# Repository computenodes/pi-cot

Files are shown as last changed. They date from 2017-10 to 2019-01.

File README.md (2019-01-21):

# Pi-iC880a



Adapter board to interface between the Raspberry Pi and the [iC880a LoRaWAN](https://wireless-solutions.de/products/radiomodules/ic880a.html) concentrator.  It also supports an EEPROM for HAT identification, DS3231 RTC chip for maintaining time between powercycles, and a [DHT-22](http://www.hobbytronics.co.uk/rht03-humidity-temp-sensor?keyword=dht22) for temperature/humidity sensing.

This board supports using 3 different GPS modules for the timing/positioning
 1. [Adafruit Ultimate GPS module](https://www.adafruit.com/product/746) soldered onto the board.  
 1. The MT3339 GPS modules (as used on the adafruit break out board) soldered directly to the PCB.  
 1. Ublox LEA-6T soldered onto the iC880a Concentrator.
 
 ## GPS Options
 In order to support the different GPS options there are solder jumpers on the PCB to link the required lines.  There are 3 jumpers: TX, RX, PPS.  The jumpers for TX & RX need to be used whichever GPS module is in use.  The PPS link is needed if using either the Ultimate GPS, or the MT3339.
 
 ## Backup battery options
 There are also pads for 0 ohm resistors to enable a choice of which peripherals have the backup battery connected.  These can either be popuplated with 0ohm resistors, or just bridged using solder.
 
 ## Enabling the UBlox module
 All GPIOs from the iC880a board are connected to the Pi.  In order to enable the UBlox module on the iC880a a couple of these need to be configured as shown below.
 
 | Pi I/O | Function | Pin State |
 | ------ | -------- | --------- |
 |  23    |  GPS  EN | HIGH      |
 |  27    | !GPS RST | HIGH      |

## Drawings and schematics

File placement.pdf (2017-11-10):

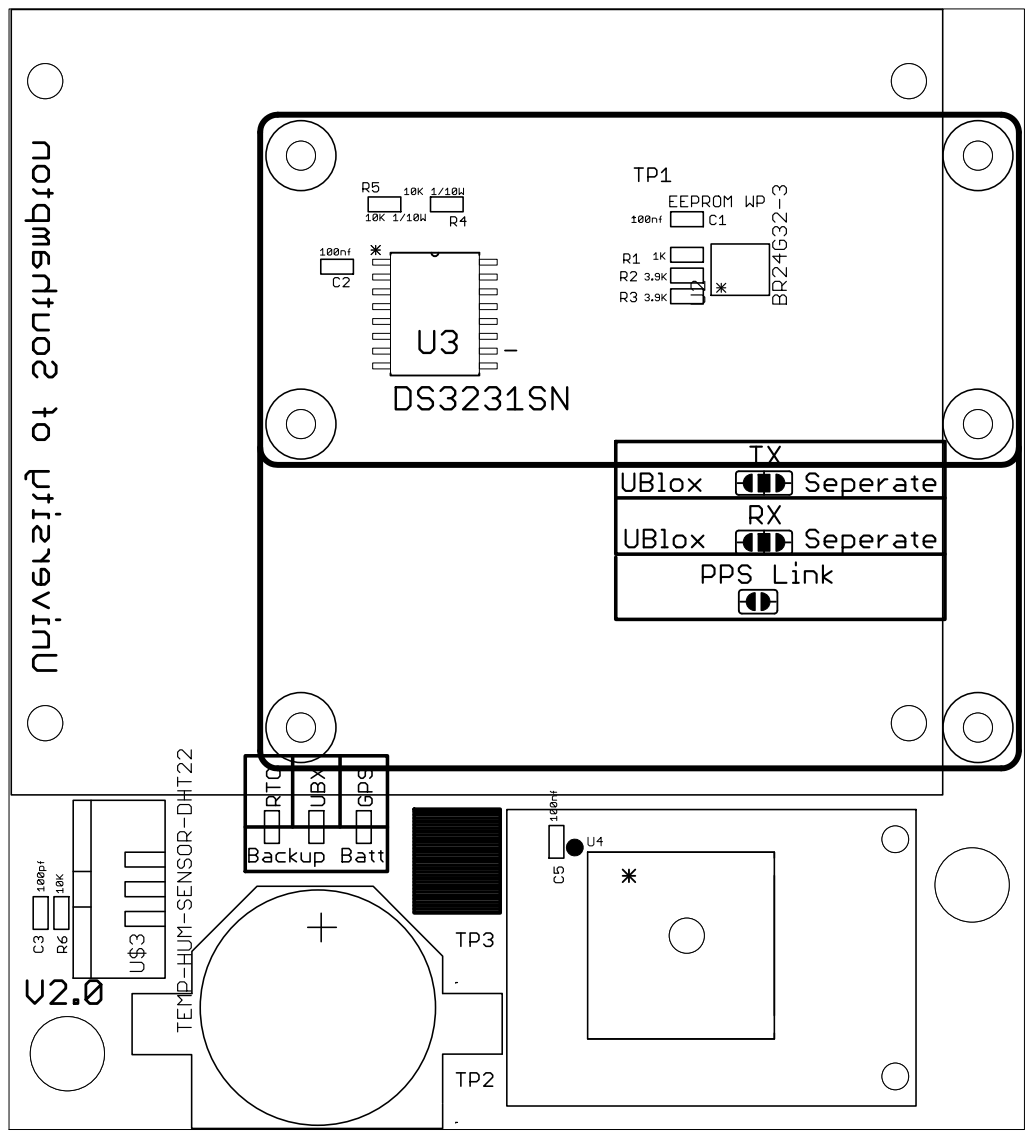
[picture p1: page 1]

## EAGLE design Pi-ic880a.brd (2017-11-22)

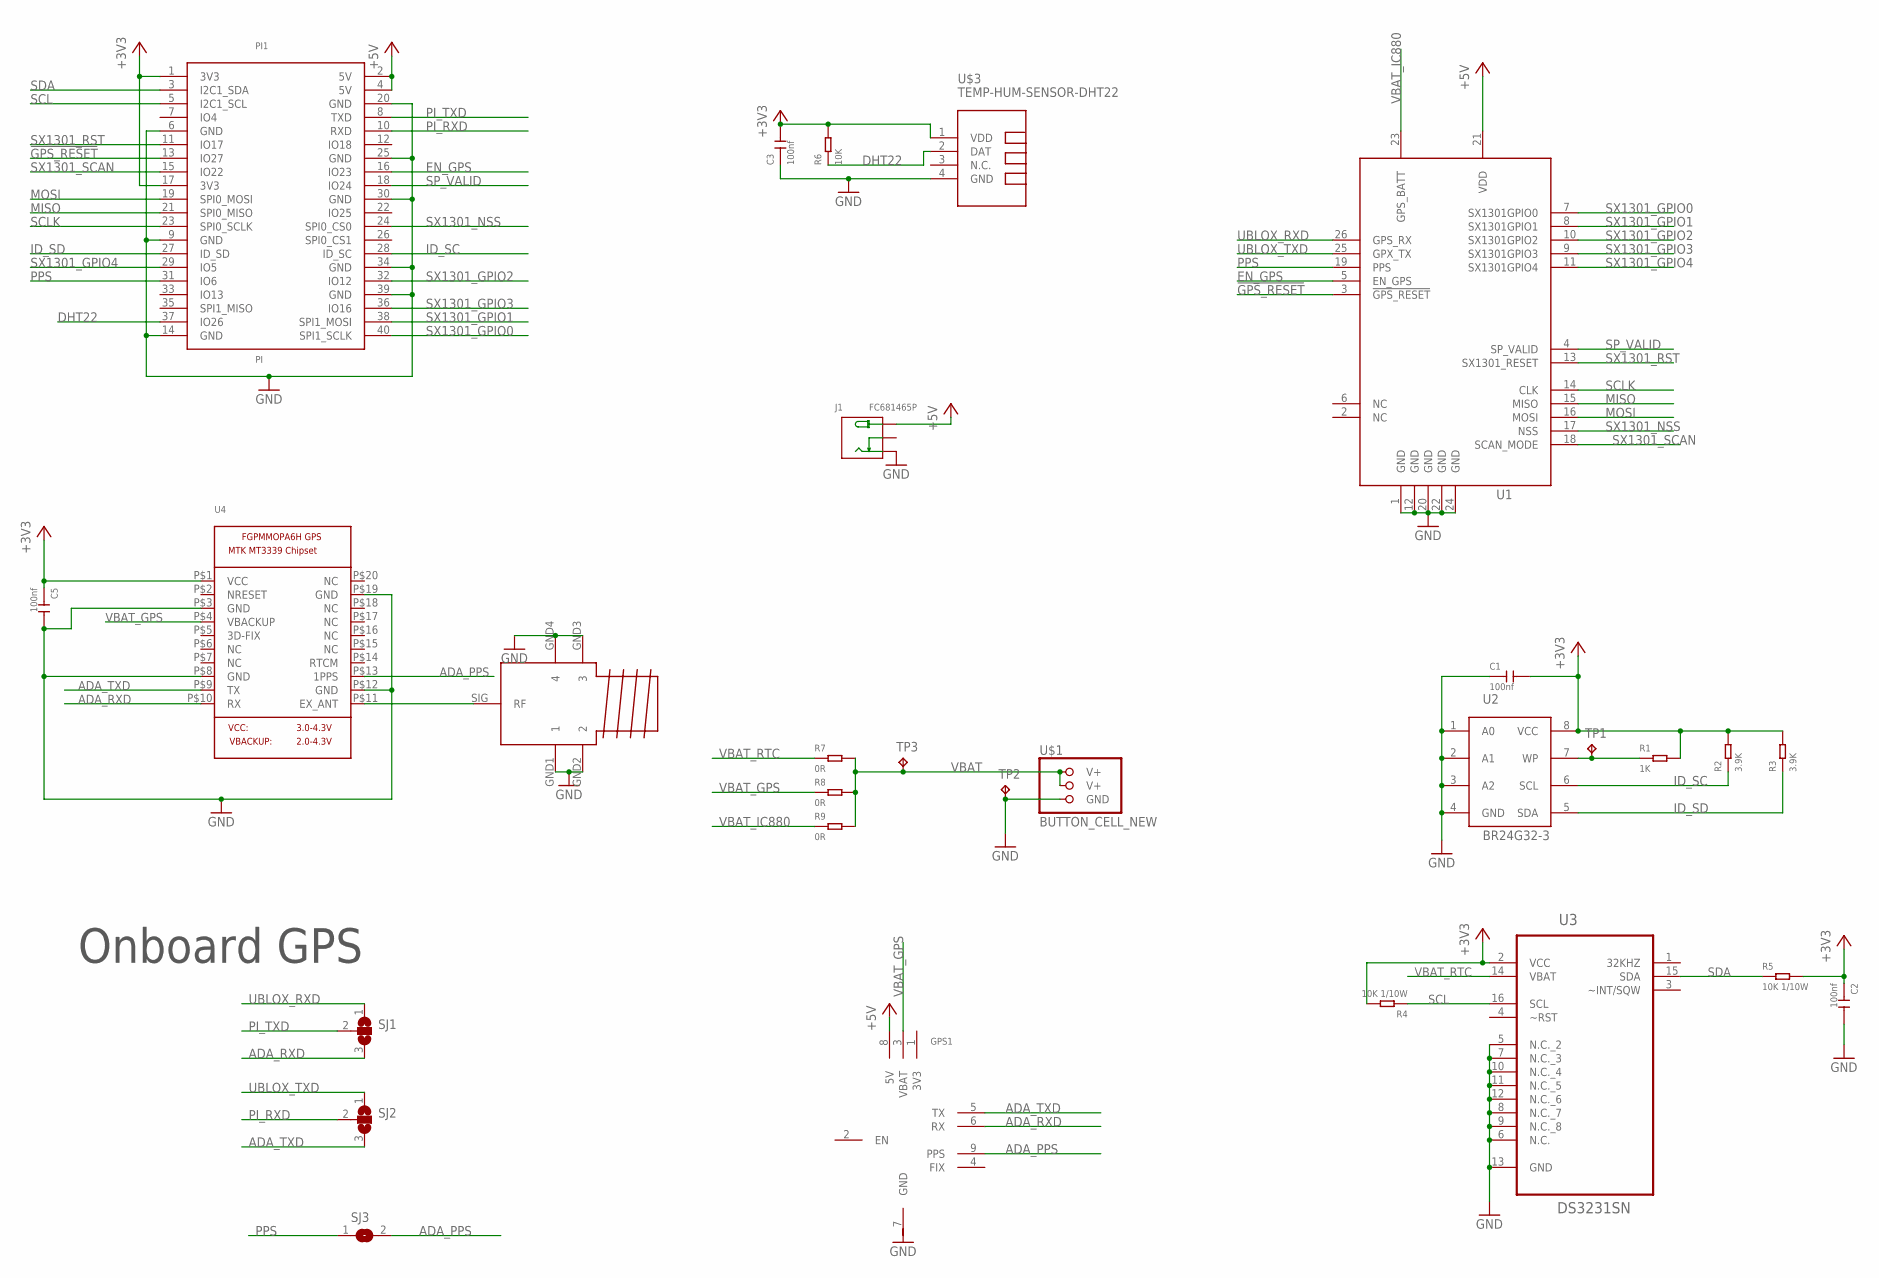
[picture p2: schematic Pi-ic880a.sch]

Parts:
C1, C2, C3, C5: 100nf; C0603
GPS1: ULTIMATE-GPS
J1: FC681465P
PI1: PI
R1: 1K; R0603
R2, R3: 3.9K; R0603
R4, R5: 10K 1/10W; R0603
R6: 10K; R0603
R7, R8, R9: 0R; R0603
SJ1, SJ2: SJ2W; SJ_2
SJ3: SJ
TP1, TP2, TP3: TPB2,54; B2,54
U1: IC880A
U2: BR24G32-3; SOP8
U3: DS3231SN; SOIC127P1032X265-16N
U4: GPS_FGPMMOPA6H; FGPMMOPA6H
U$1: BUTTON_CELL_NEW; CR2016
U$2: SMATH; SMA
U$3: TEMP-HUM-SENSOR-DHT22

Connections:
3V3: GPS1.1 (3V3)
!GPS_RESET: PI1.13 (IO27), U1.3 (!GPS_RESET)
+3V3: C1.2, C2.1, C3.2, C5.1, PI1.1 (3V3), PI1.17 (3V3), R1.2, R2.2, R3.2, R4.2, R5.2, R6.2, U2.8 (VCC), U3.2 (VCC), U4.P$1 (VCC), U$3.1 (VDD)
+5V: GPS1.8 (5V), J1.1 (+), PI1.2 (5V), PI1.4 (5V), U1.21 (VDD)
ADA_PPS: GPS1.9 (PPS), SJ3.2, U4.P$13 (1PPS)
ADA_RXD: GPS1.6 (RX), SJ1.3, U4.P$10 (RX)
ADA_TXD: GPS1.5 (TX), SJ2.3, U4.P$9 (TX)
DHT22: PI1.37 (IO26), R6.1, U$3.2 (DAT)
EN_GPS: PI1.16 (IO23), U1.5 (EN_GPS)
GND: C1.1, C2.2, C3.1, C5.2, GPS1.7 (GND), J1.3 (-), PI1.6 (GND), PI1.9 (GND), PI1.14 (GND), PI1.20 (GND), PI1.25 (GND), PI1.30 (GND), PI1.34 (GND), PI1.39 (GND), TP2.TP, U1.1 (GND), U1.12 (GND), U1.20 (GND), U1.22 (GND), U1.24 (GND), U2.1 (A0), U2.2 (A1), U2.3 (A2), U2.4 (GND), U3.5 (N.C._2), U3.6 (N.C.), U3.7 (N.C._3), U3.8 (N.C._7), U3.9 (N.C._8), U3.10 (N.C._4), U3.11 (N.C._5), U3.12 (N.C._6), U3.13 (GND), U4.P$3 (GND), U4.P$8 (GND), U4.P$12 (GND), U4.P$19 (GND), U$1.GND, U$2.GND1 (1), U$2.GND2 (2), U$2.GND3 (3), U$2.GND4 (4), U$3.4 (GND)
GPS_ANT: U4.P$11 (EX_ANT), U$2.SIG (RF)
ID_SC: PI1.28 (ID_SC), R2.1, U2.6 (SCL)
ID_SD: PI1.27 (ID_SD), R3.1, U2.5 (SDA)
MISO: PI1.21 (SPI0_MISO), U1.15 (MISO)
MOSI: PI1.19 (SPI0_MOSI), U1.16 (MOSI)
PI_RXD: PI1.10 (RXD), SJ2.2
PI_TXD: PI1.8 (TXD), SJ1.2
PPS: PI1.31 (IO6), SJ3.1, U1.19 (PPS)
SCL: PI1.5 (I2C1_SCL), R4.1, U3.16 (SCL)
SCLK: PI1.23 (SPI0_SCLK), U1.14 (CLK)
SDA: PI1.3 (I2C1_SDA), R5.1, U3.15 (SDA)
SP_VALID: PI1.18 (IO24), U1.4 (SP_VALID)
SX1301_GPIO0: PI1.40 (SPI1_SCLK), U1.7 (SX1301GPIO0)
SX1301_GPIO1: PI1.38 (SPI1_MOSI), U1.8 (SX1301GPIO1)
SX1301_GPIO2: PI1.32 (IO12), U1.10 (SX1301GPIO2)
SX1301_GPIO3: PI1.36 (IO16), U1.9 (SX1301GPIO3)
SX1301_GPIO4: PI1.29 (IO5), U1.11 (SX1301GPIO4)
SX1301_NSS: PI1.24 (SPI0_CS0), U1.17 (NSS)
SX1301_RST: PI1.11 (IO17), U1.13 (SX1301_RESET)
SX1301_SCAN: PI1.15 (IO22), U1.18 (SCAN_MODE)
UBLOX_RXD: SJ1.1, U1.26 (GPS_RX)
UBLOX_TXD: SJ2.1, U1.25 (GPX_TX)
VBAT: R7.2, R8.2, R9.2, TP3.TP, U$1.V+@1 (V+), U$1.V+@2 (V+)
VBAT_GPS: GPS1.3 (VBAT), R8.1, U4.P$4 (VBACKUP)
VBAT_IC880: R9.1, U1.23 (GPS_BATT)
VBAT_RTC: R7.1, U3.14 (VBAT)
WP: R1.1, TP1.TP, U2.7 (WP)

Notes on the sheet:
Onboard GPS

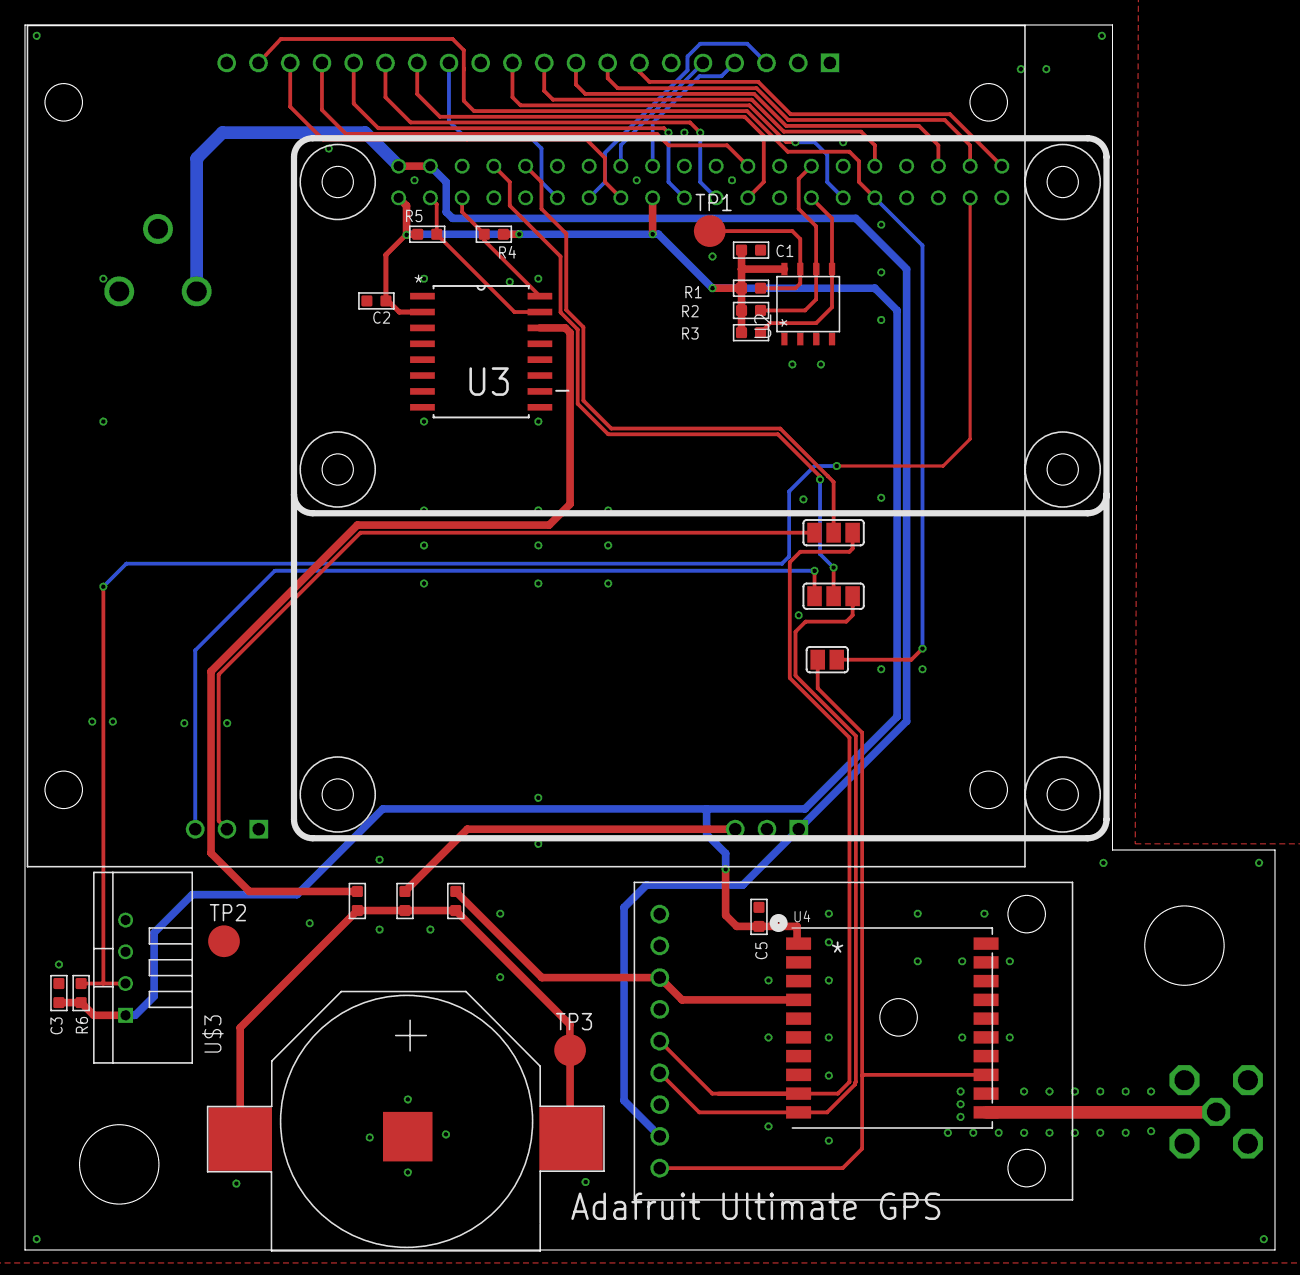
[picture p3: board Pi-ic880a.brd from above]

Board: 2 copper layers, 100.0 x 98.0 mm, 29 parts (1 on the bottom side), 36 nets.

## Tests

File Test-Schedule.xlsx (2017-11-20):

Test ID | Description | Ok
 | Pi can see EEPROM
 | Pi can programm EEPROM
 | Pi can communicate with RTC
 | RTC maintains time when power removed
 | Pi can communicate with DHT
 | SPI to ic-880 works
GPS on ic880a
 | Pi sees PPS
 | Pi can communicate with GPS
 | GPS warm starts after power removed
External GPS
 | Pi sees PPS
 | ic880a sees PPS
 | Pi can communicate with GPS
 | GPS warm starts after power removed

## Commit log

2017-07-25 First thoughts about multi-gps adapter board
    [Pi-ic880a.brd, Pi-ic880a.sch]
2017-08-01 Standalone version of the adafruit GPS module added
    [Pi-ic880a.brd, Pi-ic880a.sch]
2017-08-15 Now uses ds3231 as RTC
    [Pi-ic880a.brd, Pi-ic880a.sch]
2017-10-16 DHT22 added now fully laid out and ready for final check through
    [Pi-ic880a.brd, Pi-ic880a.sch]
2017-10-23 Added jumpers for BAT more work on labelling added test pads for VBAT
    [Pi-ic880a.brd, Pi-ic880a.sch]
2017-10-23 After adding all other GPIO
    [Pi-ic880a.brd, Pi-ic880a.sch]
2017-10-23 as submitted
    [Pi-ic880a.GBL, Pi-ic880a.GBO, Pi-ic880a.GBP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]
2017-11-10 layout names / values a bit better
    [Pi-ic880a.brd, Pi-ic880a.sch]
2017-11-10 first version of test schedule
    [Test-Schedule.xlsx]
2017-11-10 Mounting holes for adafruit module now corrected
    [Pi-ic880a.brd, Pi-ic880a.sch]
2017-11-17 Layout tweaks
    [Pi-ic880a.brd]
2017-11-20 V2 about ready to go
    [Pi-ic880a.GBL, Pi-ic880a.GBO, Pi-ic880a.GBP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]
2017-11-20 updates to test schedule
    [Test-Schedule.xlsx]
2017-11-22 DC jack added Now called Pi-CoT smd GPS moved closer to ant holes for Pi connector now bigger
    [Pi-ic880a.brd, Pi-ic880a.sch]
2017-11-22 V2 as submitted
    [Pi-ic880a.GBL, Pi-ic880a.GBO, Pi-ic880a.GBP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]
